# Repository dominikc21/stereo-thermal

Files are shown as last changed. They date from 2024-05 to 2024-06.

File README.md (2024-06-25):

# Stereo Imaging with Flir Leptons
This project aims to create a device that can be used on aerial drones or other vehicles for object detection in poor visibility conditions (fog, dust, darkness, etc.), where infrared radiation is highly visible. We achieved short-range distance measurement of detected objects up to 10 meters away, accurate to within 1-2 meters. Object detection is temperature-based, meaning that a certain temperature range is selected and bounding boxes will only be drawn around objects at this temperature. 

<div style="text-align:center">
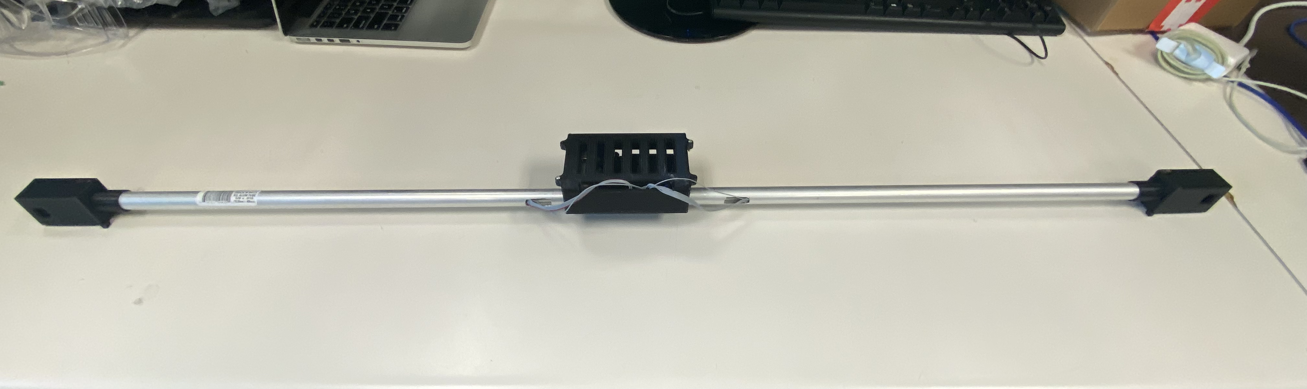
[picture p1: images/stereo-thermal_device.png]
  
</div>

## Hardware
The cameras we used in this project are the FLIR [Lepton 2.5](https://www.digikey.ca/en/products/detail/flir-lepton/500-0763-01/6250105) (60 x 80 resolution) and the [Lepton 3.5](https://www.digikey.ca/en/products/detail/flir-lepton/500-0771-01/7606616) (120 x 160). The choice not to go with both Lepton 3.5s was due to costs (~$70 CAD difference). The high-resolution camera gives a better viewing experience. Each camera was mounted on a [Lepton breakout board](https://www.digikey.ca/en/products/detail/flir-lepton/250-0577-00/10385179). We went with the Raspberry Pi 4B 8GB RAM for the computer.

## Software
The VoSPI (Video over SPI) protocol is used to gather frames in the RAW14 format (this protocol is detailed in the engineering datasheets). This portion of the software is written in C using `lWiringpi`. We originally tested it in Python, resulting in a poor frame rate. The C functions for gathering frames are called from a Python program using the `ctypes` package. To further increase the speed at which frames can be processed and displayed, we implemented separate threads to process the two input streams separately. 

## Guide

<div style="text-align:center;">
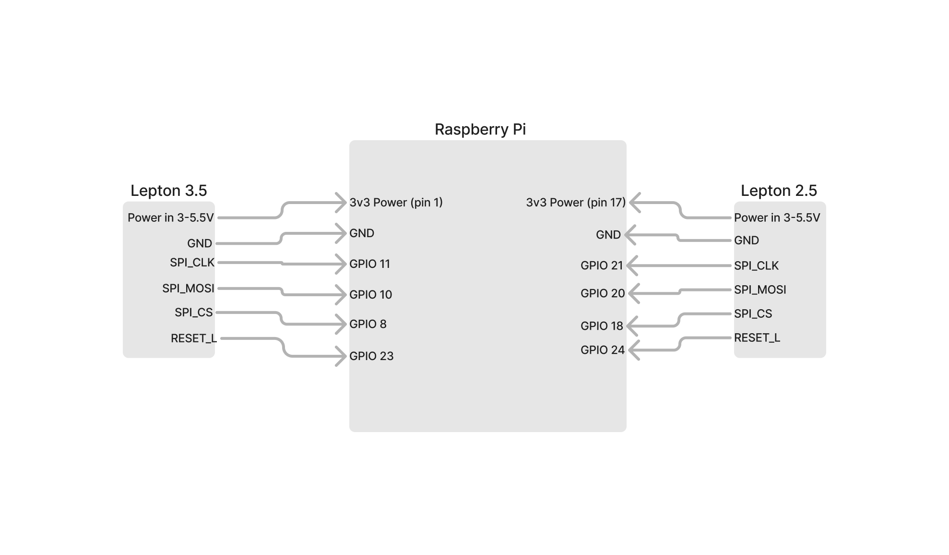
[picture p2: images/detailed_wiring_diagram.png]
  
</div>

Wire the cameras to the Raspberry Pi following the diagram above, and clone the repository. Compile `high_res.c` and `low_res.c` into shared files: `gcc -fPIC -shared -o high_res.so high_res.c -lWiringpi` in the same directory. To run the program, run `python stereo_video_threading.py`. The output will resemble the following image.

<div style="text-align:center;">
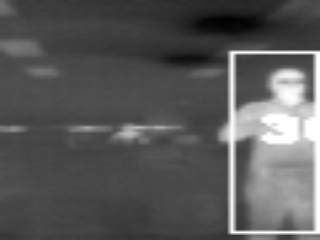
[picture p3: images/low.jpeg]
  
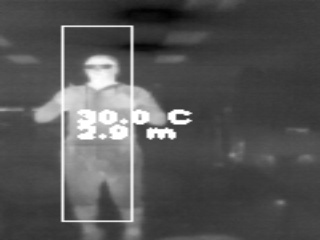
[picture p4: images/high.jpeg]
  
</div>

## Troubleshooting

- If the cameras aren't sending data (repeated `RESET1` or `RESET2` displayed in the terminal), then the best option is to unseat and reseat the camera with care. Ensure that the camera is [well-seated](https://flir.custhelp.com/app/answers/detail/a_id/5750/~/flir-oem---lepton-2.5-and-3.5-enclosure-assembly).

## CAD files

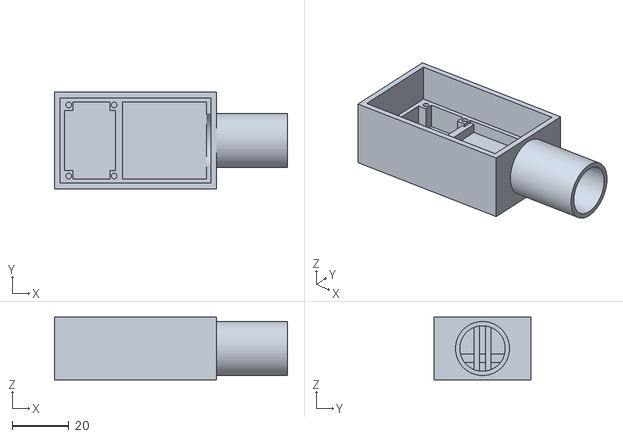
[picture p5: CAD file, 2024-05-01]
STL-files/Camera_case_v3.stl
82.0 x 34.0 x 22.0

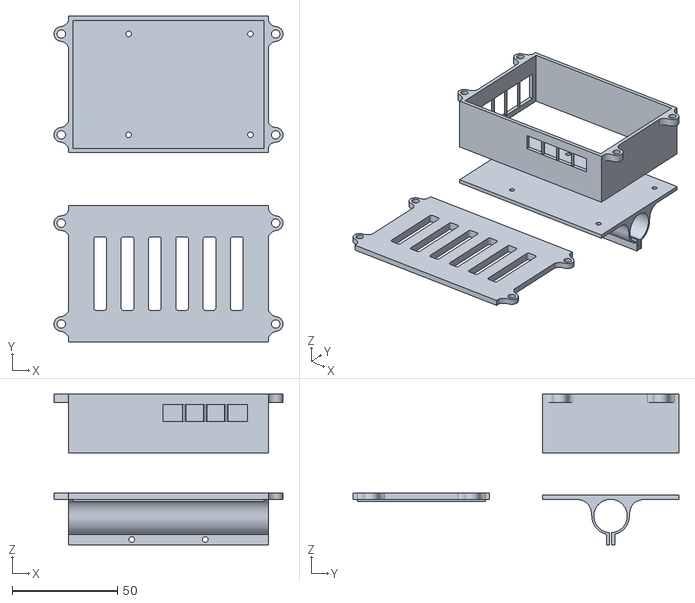
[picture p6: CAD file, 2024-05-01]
STL-files/RaspberryPi_box_capstone_v3.stl
109.0 x 155.0 x 71.7

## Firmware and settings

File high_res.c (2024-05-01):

#include <stdint.h>
#include <unistd.h>
#include <stdio.h>
#include <stdlib.h>
#include <getopt.h>
#include <fcntl.h>
#include <sys/ioctl.h>
#include <linux/types.h>
#include <linux/spi/spidev.h>
#include <limits.h>
#include <dlfcn.h>
#include <wiringPi.h>
#include <time.h>

static void pabort(const char *s)
{
	perror(s);
	abort();
}

static const char *lep3 = "/dev/spidev0.0";
static uint8_t mode;
static uint8_t bits = 8;
static uint32_t speed = 24000000;
static uint16_t delayy;

#define VOSPI_FRAME_SIZE (164)
uint8_t lepton_frame_packet[VOSPI_FRAME_SIZE];

int lepton3_1d[120*160];

void adjust()
{
	int i, j;
	int max_i, max_j;
	unsigned int maxval = 0;
	unsigned int minval = UINT_MAX;
	

	//printf("Calculating min/max values for proper scaling...\n");
	for (i = 0; i < 19200; i++)
	{
		if ((lepton3_1d[i] > maxval) && (lepton3_1d[i] != UINT_MAX))
		{
			maxval = lepton3_1d[i];
		}
		if ((lepton3_1d[i] < minval) && (lepton3_1d[i] != 0))
		{
			minval = lepton3_1d[i];
		}
	}
	for (i = 0; i < 19200; i++)
	{
		//lepton3_1d[i] -= minval;
	}

}


int transfer(int fd) {
	int ret;
	int frame_number;
	uint8_t tx[VOSPI_FRAME_SIZE] = {};
	struct spi_ioc_transfer tr = {
		.tx_buf = (unsigned long)tx,
		.rx_buf = (unsigned long)lepton_frame_packet,
		.len = VOSPI_FRAME_SIZE,
		.delay_usecs = delayy,
		.speed_hz = speed,
		.bits_per_word = bits,
	};

	int discard = 0;
	int segment = 1;
	while (segment < 5)
	{
		int packet = 0;
		while (packet < 60) 
		{
			ret = ioctl(fd, SPI_IOC_MESSAGE(1), &tr);
		
			if (ret < 1)
				pabort("can't send spi message");
			
			if ((lepton_frame_packet[0]&0xf) != 0x0f)
			{
				frame_number = lepton_frame_packet[1];
				if ((frame_number > 59))
				{
					// SYNC
					//if (discard > 1000) {
					
						wiringPiSetup();
						pinMode(1, OUTPUT);
						digitalWrite(1, HIGH);
						clock_t start_time = clock();
						printf("SYNC2\n");
						while (clock() < start_time + 200000);
						digitalWrite(1, LOW);
					
					//}
					discard ++;
					
					packet = 0;
					continue;
				}
				
				if ((frame_number == 20) && ((lepton_frame_packet[0] >> 4) != segment))
				{
					
					//if (discard > 1000) {
					/*
						wiringPiSetup();
						pinMode(1, OUTPUT);
						digitalWrite(1, HIGH);
						clock_t start_time = clock();
						printf("SYNC2\n");
						while (clock() < start_time + 200000);
						digitalWrite(1, LOW);
					*/
					//}
					discard ++;
					
					packet = 0;
					continue;
				}
				if (packet == frame_number)
				{
					for(int i=0;i<80;i++)
					{
						lepton3_1d[i + packet*80 + (segment-1)*4800] = ((lepton_frame_packet[2*i+4] << 8 | lepton_frame_packet[2*i+5]) >> 2);
					}

					packet ++;
					
				}
			}
			else
			{
				discard ++;
				
				if (discard > 20000)
				{
					// RESET
					
					wiringPiSetup();
				    pinMode(4, OUTPUT);
					digitalWrite(4, LOW);
					clock_t start_time = clock();
					printf("RESET2\n");
					while (clock() < start_time + 100000);
					digitalWrite(4, HIGH);
					while (clock() < start_time + 6000000);
					
					return 1;
				}
			}
		}
		segment ++;
	}
	return 0;
}


void check(int fd) {
	int ret = 0;
	
	if (fd < 0)
	{
		pabort("can't open device");
	}

	ret = ioctl(fd, SPI_IOC_WR_MODE, &mode);
	if (ret == -1)
	{
		pabort("can't set spi mode");
	}

	ret = ioctl(fd, SPI_IOC_RD_MODE, &mode);
	if (ret == -1)
	{
		pabort("can't get spi mode");
	}

	ret = ioctl(fd, SPI_IOC_WR_BITS_PER_WORD, &bits);
	if (ret == -1)
	{
		pabort("can't set bits per word");
	}

	ret = ioctl(fd, SPI_IOC_RD_BITS_PER_WORD, &bits);
	if (ret == -1)
	{
		pabort("can't get bits per word");
	}

	ret = ioctl(fd, SPI_IOC_WR_MAX_SPEED_HZ, &speed);
	if (ret == -1)
	{
		pabort("can't set max speed hz");
	}

	ret = ioctl(fd, SPI_IOC_RD_MAX_SPEED_HZ, &speed);
	if (ret == -1)
	{
		pabort("can't get max speed hz");
	}

	//printf("spi mode: %d\n", mode);
	//printf("bits per word: %d\n", bits);
	//printf("max speed: %d Hz (%d MHz)\n", speed, speed/1000000);
} 

int *lepton3(void) {
	int ret = 0;
	int fd;
	fd = open(lep3, O_RDWR);
	
	while (transfer(fd) != 0);
	check(fd);
	
	//transfer(fd);
	
	close(fd);
	adjust();

	return lepton3_1d;
}

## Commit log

2024-05-01 Create STL folder
2024-05-01 added stl files
    [Camera_case_v3.stl, RaspberryPi_box_capstone_v3.stl]
